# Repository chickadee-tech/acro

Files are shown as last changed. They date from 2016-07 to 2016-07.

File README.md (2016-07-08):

# Chickadee Tech Acro Polystack Mod #
This mod connects an MPU-6500 to the base control board. It is not in active production.

## Documentation ##
See the [wiki](https://github.com/chickadee-tech/acro/wiki) for documentation.

## Polystack ##
This **mod** board is part of the Polystack platform for modular microcontrol systems. More information on the platform can be found at [polystack.org](http://polystack.org).

## Support ##
If you need support with a board you own or have development questions please email support@chickadee.tech or check [chickadee.tech/support](https://chickadee.tech/support) for other ways to get support.

## Contributing ##
Please note that this project is released with a [Contributor Code of Conduct](CODE_OF_CONDUCT.md). By participating in this project you agree to abide by its terms.

### Setup ###
Components and footprints for PCB parts are not included in this repository. Instead, checkout the [chickadee-tech/kicad-libs](https://github.com/chickadee-tech/kicad-libs) repository in the same directory that this repository is checked out in. All part definitions should be relative so that they will load correctly.

### Pull requests ###
For fixes please submit a pull request to the original repository. After the pull request is merged, check the [Chickadee Tech Active Contributor Discount (ACD)](https://chickadee.tech/active-contributor) to see if you are eligible for a discount code to use on your next purchase.

### Derivatives ###
If developing your own version of the Acro board please remove all Chickadee Tech trademarks and follow the [CC-BY license](LICENSE). While not required, please consider open sourcing your modifications so others can learn from your improvements. If you do email support@chickadee.tech and we may choose to add your project to the ACD.

You may also license the Polystack logo for free by emailing support@chickadee.tech. We'll ask for your gerbers to ensure the design complies with specifications laid out [here](https://github.com/chickadee-tech/polystack/wiki) and provide written permission to use the trademark after compliance has been demonstrated.

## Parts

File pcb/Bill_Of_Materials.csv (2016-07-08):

part name | symbol | size (imp) | max current | unit price | units per build | units in stock | order total | Manufacturer ID | source url | MacroFab House Part | datasheet
80 pin header | PORT_IN1 |  |  | $1.35 | 1 | 1 | $1.35 | DF40C-80DP-0.4V(51) | http://www.digikey.com/product-detail/en/DF40C-80DP-0.4V(51)/H11632CT-ND/1969511 | N | http://www.hirose.co.jp/cataloge_hp/ed_DF40_20140305.pdf | Total Base Cost | $19.38
80 pin receptacle (2.0mm) | PORT_OUT1 |  |  | $1.90 | 1 | 2 | $1.90 | DF40C(2.0)-80DS-0.4V(51) | http://www.digikey.com/product-detail/en/DF40C(2.0)-80DS-0.4V(51)/H11773CT-ND/2178736 | N | http://www.hirose.co.jp/cataloge_hp/ed_DF40_20140305.pdf
AND/OR gate | PORT_ANDOR1 |  |  | $0.25 | 1 | 2 | $0.25 | SN74LVC1G0832DCKR | http://www.digikey.com/product-detail/en/SN74LVC1G0832DCKR/296-18754-1-ND/863884 |  | http://www.ti.com/lit/ds/symlink/sn74lvc1g0832.pdf
multifunction gate | PORT_XOR1, PORT_INV1 |  |  | $0.14 | 2 | 6 | $0.28 | SN74LVC1G58DCKR | http://www.digikey.com/product-detail/en/SN74LVC1G58DCKR/296-15577-1-ND/571153 |  | http://www.ti.com/lit/ds/symlink/sn74lvc1g58.pdf
64kbit eeprom | PORT_IC1 | udfn |  | $0.61 | 1 | 2 | $0.61 | AT24CS64-MAHM-T | http://www.digikey.com/product-detail/en/AT24CS64-MAHM-T/AT24CS64-MAHM-TCT-ND/4292118 | N | http://www.atmel.com/images/atmel-8870-seeprom-at24cs64-datasheet.pdf
acc/gyro | U1 | 24pin QFN 3x3 |  | $10.72 | 1 | 2 | $10.72 | MPU-6500 | http://www.digikey.com/product-detail/en/MPU-6500/1428-1011-1-ND/4385413 | N | http://store.invensense.com/datasheets/invensense/MPU_6500_Rev1.0.pdf
n-channel mosfet | Q1 | TO-236-3, SC-59, SOT-23-3 | 220mA continuous | $0.09 | 1 | 59 | $0.09 | bss138 | http://www.digikey.com/product-detail/en/BSS138/BSS138CT-ND/244294 | MF-DSC-SOT233-BSS138 | https://www.fairchildsemi.com/datasheets/BS/BSS138.pdf
3.3v regulator | U2 | SOT23-5 | 0.3A | $0.49 | 1 | 8 | $0.49 | TLV70233DBVR | http://www.digikey.com/product-detail/en/TLV70233DBVR/296-32415-1-ND/3505572 | MF-REG-SOT235-3.3V-300mA | http://www.ti.com/lit/ds/symlink/tlv702.pdf
R 100k | R1 | 603 |  | $0.01 | 1 | 55 | $0.01 | RC0603FR-07100KL | http://www.digikey.com/product-detail/en/RC0603FR-07100KL/311-100KHRCT-ND/729836 | MF-RES-0603-100K | http://www.yageo.com/NewPortal/yageodocoutput?fileName=/pdf/R-Chip/PYu-RC_Group_51_RoHS_L_3.pdf
R 1k | R2 | 603 |  | $0.01 | 1 | 993 | $0.01 | RC0603FR-071KL | http://www.digikey.com/product-detail/en/RC0603FR-071KL/311-1.00KHRCT-ND/729790 | MF-RES-0603-1K | http://www.yageo.com/NewPortal/yageodocoutput?fileName=/pdf/R-Chip/PYu-RC_Group_51_RoHS_L_3.pdf
red led | D1 |  |  | $0.19 | 1 | 71 | $0.19 | LTST-C190KRKT | http://www.digikey.com/product-detail/en/LTST-C190KRKT/160-1436-1-ND/386816 | MF-LED-0603-RED | http://optoelectronics.liteon.com/upload/download/DS-22-99-0151/S_110_LTST-C190KRKT.pdf
C 10nF (0.01uF, 10000pF) X7R | C1 | 603 |  | $0.01 | 1 | 96 | $0.01 | 06035C103KAT2A | http://www.digikey.com/product-detail/en/06035C103KAT2A/478-1227-1-ND/564259 | Y | http://datasheets.avx.com/X7RDielectric.pdf
C 0.1uF | C2, C3 | 603 |  | $0.02 | 2 | 400 | $0.04 | C0603C104K4RACTU | http://www.digikey.com/product-detail/en/C0603C104K4RACTU/399-1096-1-ND/411371 | MF-CAP-0603-0.1uF | http://www.kemet.com/docfinder?Partnumber=C0603C104K4RACTU
C 1uF X7R | C4, C5 | 603 |  | $0.03 | 2 | 20 | $0.06 | TMK107B7105KA-T | http://www.digikey.com/product-detail/en/TMK107B7105KA-T/587-2984-1-ND/2714177 | MF-CAP-0603-1uF | http://ds.yuden.co.jp/TYCOMPAS/ut/detail.do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
Chickadee Acro v1 | PCB |  |  | $3.37 | 1 | 2 | $3.37 | CKD-ACRO-V1 |  | N

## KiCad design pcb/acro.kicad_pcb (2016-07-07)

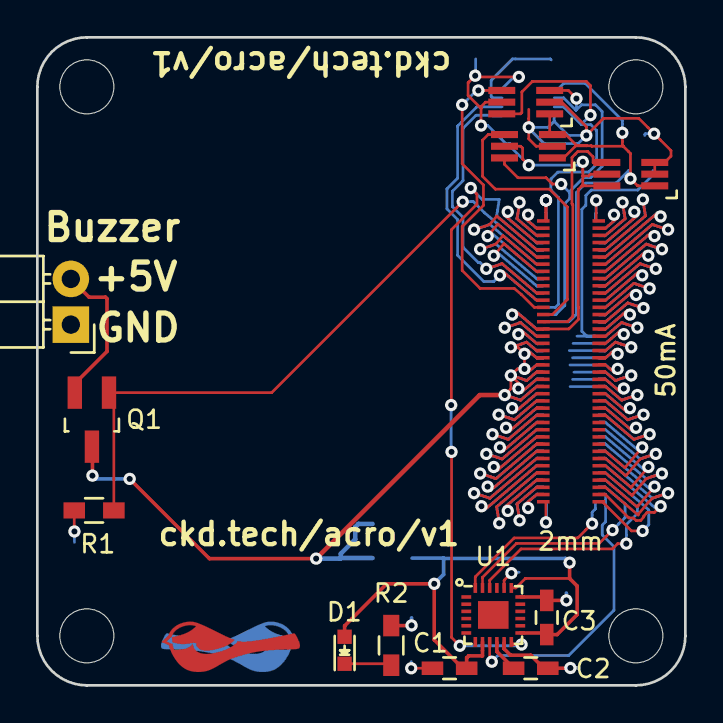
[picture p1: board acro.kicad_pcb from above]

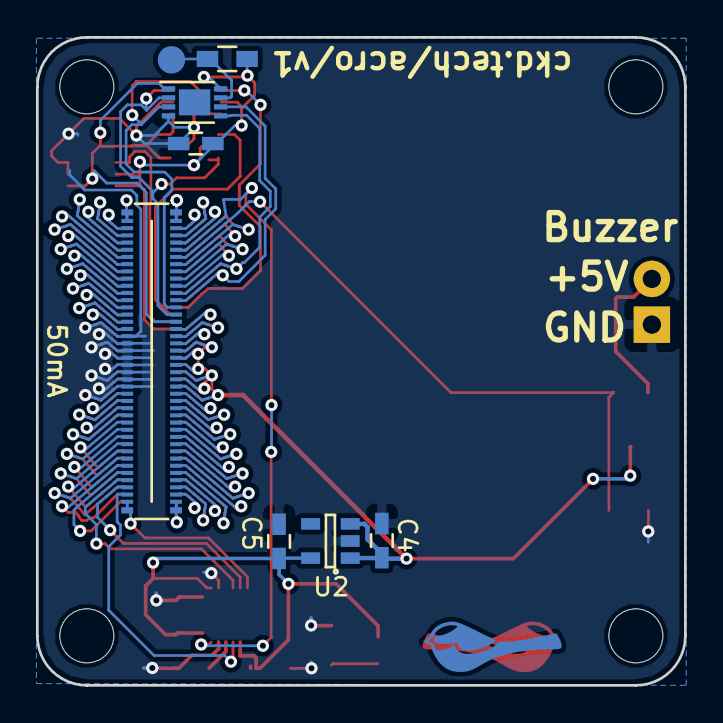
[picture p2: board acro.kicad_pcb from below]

Board: 2 copper layers, 36.0 x 36.0 mm, 21 parts (8 on the bottom side), 76 nets.

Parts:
C1: 10nF; C_0603_HandSoldering
C2, C3: 0.1uF; C_0603_HandSoldering
C4, C5: 1uF; C_0603_HandSoldering
D1: LED; LED-0603
P1: CONN_01X02; Pin_Header_Angled_1x02
PORT_ANDOR1: SN74LVC1G0832; SC-70-6_Handsoldering
PORT_C1: 0.1uF; C_0603_HandSoldering
PORT_IC1: AT24CS02-MAHM; DFN-8-1EP_3x2mm_Pitch0.5mm
PORT_IN1: CKD_SANDWICH; DF40-80pin-Header
PORT_INV1: SN74LVC1G58; SC-70-6_Handsoldering
PORT_OUT1: CKD_SANDWICH; DF40-3-4mm-80pin-Receptacle
PORT_P1: CONN_01X01; Measurement_Point_Round-SMD-Pad_Small
PORT_R1: 10k; R_0603_HandSoldering
PORT_XOR1: SN74LVC1G58; SC-70-6_Handsoldering
Q1: Q_NMOS_GSD; SOT-23_Handsoldering
R1: 100k; R_0603_HandSoldering
R2: 1k; R_0603_HandSoldering
U1: MPU-6500; QFN-24-1EP_3x3mm_Pitch0.4mm
U2: TLV70233DBV; SOT-23-5

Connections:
+3V3: C1.1, C3.1, C5.1, D1.2, U1.8, U1.13, U1.19, U2.5
+5V: C4.1, PORT_IN1.19, PORT_IN1.20, PORT_IN1.21, PORT_IN1.22, PORT_IN1.23, PORT_IN1.24, PORT_OUT1.19, PORT_OUT1.20, PORT_OUT1.21, PORT_OUT1.22, PORT_OUT1.23, PORT_OUT1.24, Q1.3, U2.1, U2.3
/ExpansionPort/3V3_0.3A_E: PORT_IN1.17, PORT_OUT1.17
/ExpansionPort/3V3_0.3A_LL: PORT_ANDOR1.5, PORT_C1.1, PORT_IC1.8, PORT_IN1.16, PORT_INV1.5, PORT_INV1.6, PORT_OUT1.16, PORT_R1.2, PORT_XOR1.5
/ExpansionPort/+BATT: PORT_IN1.18, PORT_OUT1.18
/ExpansionPort/ADC1: PORT_IN1.49, PORT_OUT1.49
/ExpansionPort/ADC2: PORT_IN1.50, PORT_OUT1.50
/ExpansionPort/BOOT: PORT_IN1.65, PORT_OUT1.65
/ExpansionPort/CAN_HI: PORT_IN1.67, PORT_OUT1.67
/ExpansionPort/CAN_LO: PORT_IN1.68, PORT_OUT1.68
/ExpansionPort/GPIO1: PORT_IN1.5, U1.12
/ExpansionPort/GPIO2: PORT_IN1.6, Q1.1, R1.1
/ExpansionPort/GPIO3: PORT_IN1.7, PORT_OUT1.5
/ExpansionPort/GPIO4: PORT_IN1.8, PORT_OUT1.6
/ExpansionPort/GPIO5: PORT_IN1.9, PORT_OUT1.7
/ExpansionPort/GPIO6: PORT_IN1.10, PORT_OUT1.8
/ExpansionPort/HEIGHT_1: PORT_ANDOR1.1, PORT_IC1.1, PORT_IN1.15, PORT_INV1.1, PORT_XOR1.1, PORT_XOR1.3
/ExpansionPort/HEIGHT_2: PORT_ANDOR1.3, PORT_IC1.2, PORT_IN1.14, PORT_XOR1.6
/ExpansionPort/HEIGHT_4: PORT_ANDOR1.6, PORT_IC1.3, PORT_IN1.13
/ExpansionPort/NEW_HEIGHT_1: PORT_INV1.4, PORT_OUT1.15
/ExpansionPort/NEW_HEIGHT_2: PORT_OUT1.14, PORT_XOR1.4
/ExpansionPort/NEW_HEIGHT_4: PORT_ANDOR1.4, PORT_OUT1.13
/ExpansionPort/RESET: PORT_IN1.66, PORT_OUT1.66
/ExpansionPort/SDMMC1_CK: PORT_IN1.55, PORT_OUT1.55
/ExpansionPort/SDMMC1_CMD: PORT_IN1.56, PORT_OUT1.56
/ExpansionPort/SDMMC1_D0: PORT_IN1.51, PORT_OUT1.51
/ExpansionPort/SDMMC1_D1: PORT_IN1.52, PORT_OUT1.52
/ExpansionPort/SDMMC1_D2: PORT_IN1.53, PORT_OUT1.53
/ExpansionPort/SDMMC1_D3: PORT_IN1.54, PORT_OUT1.54
/ExpansionPort/SPI1_MISO: PORT_IN1.79, U1.9
/ExpansionPort/SPI1_MOSI: PORT_IN1.80, U1.24
/ExpansionPort/SPI1_NSS: PORT_IN1.77, U1.22
/ExpansionPort/SPI1_SCK: PORT_IN1.78, U1.23
/ExpansionPort/SPI2_MISO: PORT_IN1.75, PORT_OUT1.79
/ExpansionPort/SPI2_MOSI: PORT_IN1.76, PORT_OUT1.80
/ExpansionPort/SPI2_NSS: PORT_IN1.73, PORT_OUT1.77
/ExpansionPort/SPI2_SCK: PORT_IN1.74, PORT_OUT1.78
/ExpansionPort/SPI3_MISO: PORT_IN1.71, PORT_OUT1.75
/ExpansionPort/SPI3_MOSI: PORT_IN1.72, PORT_OUT1.76
/ExpansionPort/SPI3_NSS: PORT_IN1.69, PORT_OUT1.73
/ExpansionPort/SPI3_SCK: PORT_IN1.70, PORT_OUT1.74
/ExpansionPort/TIM1: PORT_IN1.1, PORT_OUT1.1
/ExpansionPort/TIM2: PORT_IN1.2, PORT_OUT1.2
/ExpansionPort/TIM3: PORT_IN1.3, PORT_OUT1.3
/ExpansionPort/TIM4: PORT_IN1.4, PORT_OUT1.4
/ExpansionPort/TIMG1_CH1: PORT_IN1.41, PORT_OUT1.41
/ExpansionPort/TIMG1_CH2: PORT_IN1.42, PORT_OUT1.42
/ExpansionPort/TIMG1_CH3: PORT_IN1.43, PORT_OUT1.43
/ExpansionPort/TIMG1_CH4: PORT_IN1.44, PORT_OUT1.44
/ExpansionPort/TIMG2_CH1: PORT_IN1.45, PORT_OUT1.45
/ExpansionPort/TIMG2_CH2: PORT_IN1.46, PORT_OUT1.46
/ExpansionPort/TIMG2_CH3: PORT_IN1.47, PORT_OUT1.47
/ExpansionPort/TIMG2_CH4: PORT_IN1.48, PORT_OUT1.48
/ExpansionPort/UART1_RX: PORT_IN1.40, PORT_OUT1.40
/ExpansionPort/UART1_TX: PORT_IN1.39, PORT_OUT1.39
/ExpansionPort/UART2_RX: PORT_IN1.38, PORT_OUT1.38
/ExpansionPort/UART2_TX: PORT_IN1.37, PORT_OUT1.37
/ExpansionPort/UART3_RX: PORT_IN1.36, PORT_OUT1.36
/ExpansionPort/UART3_TX: PORT_IN1.35, PORT_OUT1.35
/ExpansionPort/UART4_RX: PORT_IN1.34, PORT_OUT1.34
/ExpansionPort/UART4_TX: PORT_IN1.33, PORT_OUT1.33
/ExpansionPort/UART5_RX: PORT_IN1.32, PORT_OUT1.32
/ExpansionPort/UART5_TX: PORT_IN1.31, PORT_OUT1.31
/ExpansionPort/UART6_RX: PORT_IN1.30, PORT_OUT1.30
/ExpansionPort/UART6_TX: PORT_IN1.29, PORT_OUT1.29
/ExpansionPort/UART7_RX: PORT_IN1.28, PORT_OUT1.28
/ExpansionPort/UART7_TX: PORT_IN1.27, PORT_OUT1.27
/ExpansionPort/UART8_RX: PORT_IN1.26, PORT_OUT1.26
/ExpansionPort/UART8_TX: PORT_IN1.25, PORT_OUT1.25
/ExpansionPort/i2c_SCL: PORT_IC1.6, PORT_IN1.12, PORT_OUT1.12
/ExpansionPort/i2c_SDA: PORT_IC1.5, PORT_IN1.11, PORT_OUT1.11
GNDPWR: C1.2, C2.2, C3.2, C4.2, C5.2, P1.1, PORT_ANDOR1.2, PORT_C1.2, PORT_IC1.4, PORT_IN1.57, PORT_IN1.58, PORT_IN1.59, PORT_IN1.60, PORT_IN1.61, PORT_IN1.62, PORT_IN1.63, PORT_IN1.64, PORT_INV1.2, PORT_INV1.3, PORT_OUT1.57, PORT_OUT1.58, PORT_OUT1.59, PORT_OUT1.60, PORT_OUT1.61, PORT_OUT1.62, PORT_OUT1.63, PORT_OUT1.64, PORT_XOR1.2, R1.2, R2.2, U1.11, U1.18, U1.20, U2.2
unnamed: C2.1, U1.10
unnamed: D1.1, R2.1
unnamed: P1.2, Q1.2
unnamed: PORT_IC1.7, PORT_P1.1, PORT_R1.1

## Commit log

2015-12-21 v1 of the acro module
    [ExpansionPort.sch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]
2016-01-07 change pull up resistor value
    [acro.kicad_pcb, acro.sch]
2016-07-07 Add license information to many files. PCB design files are CC-BY and code is MIT license.
    [ExpansionPort.sch, acro.kicad_pcb, acro.sch]
2016-07-07 Convert to relative component and footprint paths.
    [ExpansionPort.sch, acro.sch]
2016-07-08 Add BOM
    [Bill_Of_Materials.csv]
2016-07-08 Change column header in BOM
    [Bill_Of_Materials.csv]

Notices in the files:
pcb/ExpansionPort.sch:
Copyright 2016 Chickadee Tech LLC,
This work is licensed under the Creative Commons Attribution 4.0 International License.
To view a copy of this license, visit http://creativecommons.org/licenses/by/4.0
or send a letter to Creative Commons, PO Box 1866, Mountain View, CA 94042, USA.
